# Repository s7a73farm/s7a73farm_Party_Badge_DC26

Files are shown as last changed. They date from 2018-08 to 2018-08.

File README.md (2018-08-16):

# s7a73farmsPartyBadge

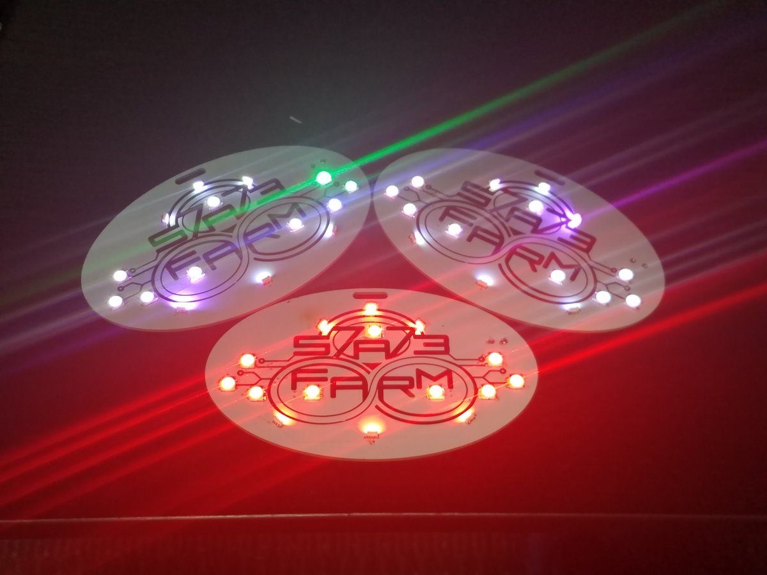
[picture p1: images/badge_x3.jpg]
s7a73farmsPartyBadge


# Getting Started to program it
```
Modify the tx/Makefile & rx/Makefile 
Line 16: AVRDUDE = avrdude -c usbasp -p t84 -U flash:w:$(PROJECT).hex
Change usbasp to usbtiny or whatever programmer  you are using.
```

## Build Master Badge
```
git clone git@github.com:SocialGeeks/s7a73farmsPartyBadge.git
cd firmware/tx
make clean
make
make upload
```

## Build Slave Badge
```
git clone git@github.com:SocialGeeks/s7a73farmsPartyBadge.git
cd firmware/rx
make clean
make
make upload
```

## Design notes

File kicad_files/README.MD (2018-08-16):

# FILES
---------------------
Gerbers zip

Kicad project zip

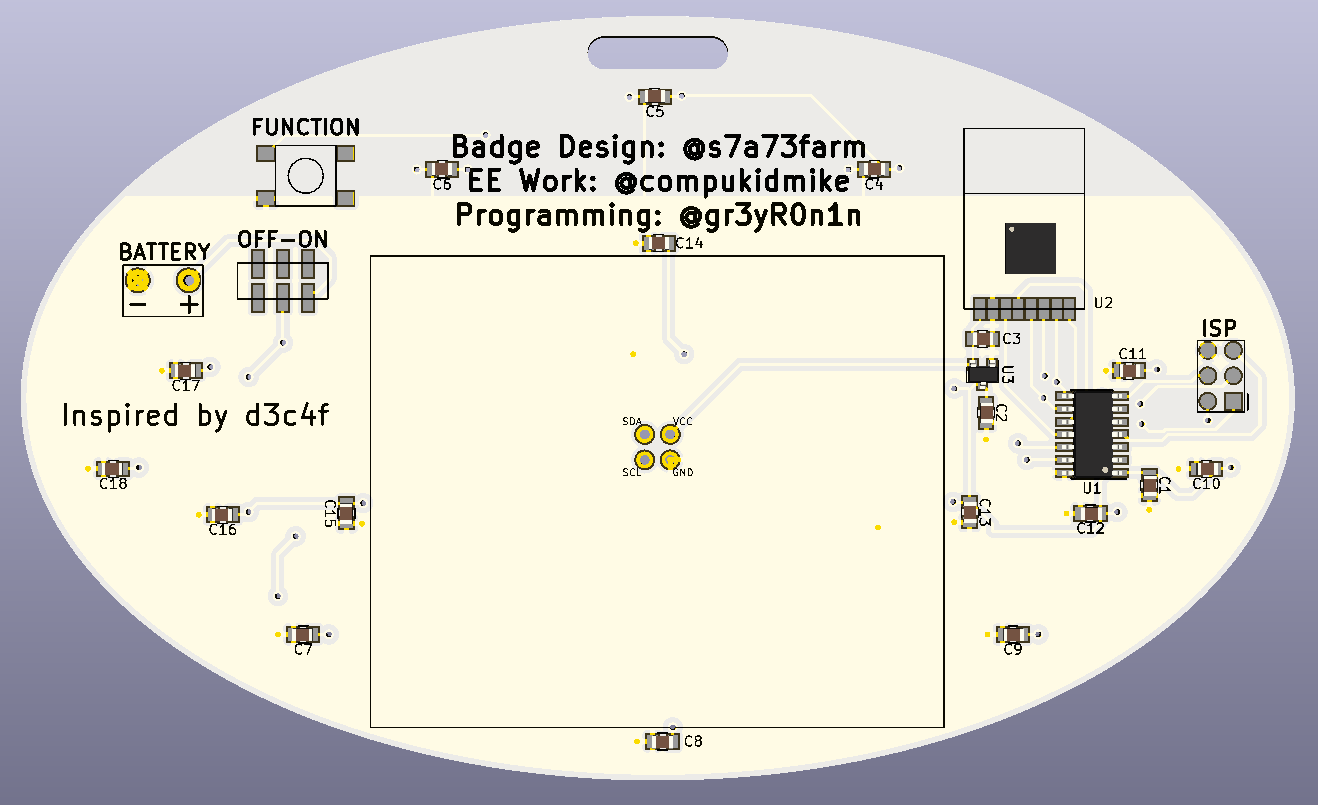
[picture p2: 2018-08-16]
images/Render2.PNG

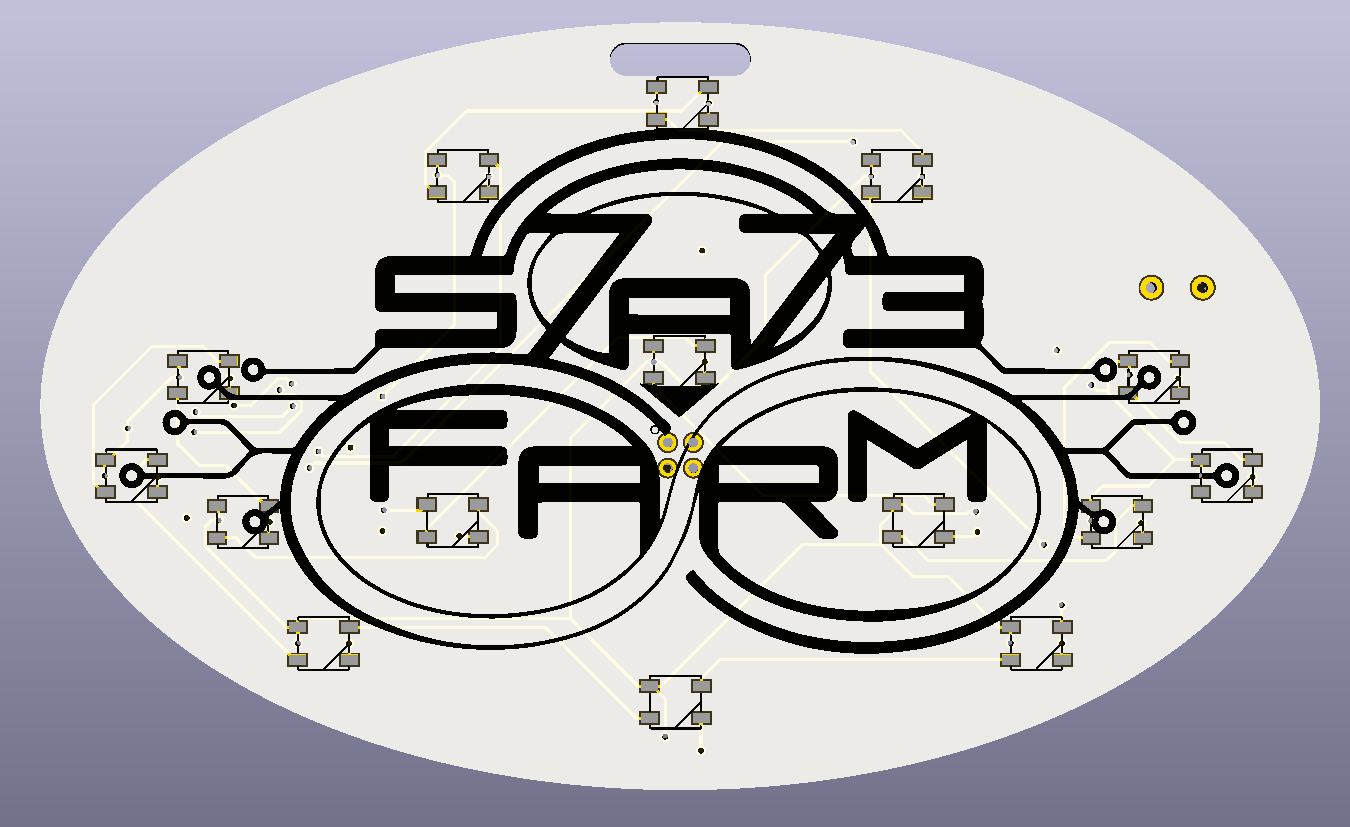
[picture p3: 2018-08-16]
images/Render1.PNG

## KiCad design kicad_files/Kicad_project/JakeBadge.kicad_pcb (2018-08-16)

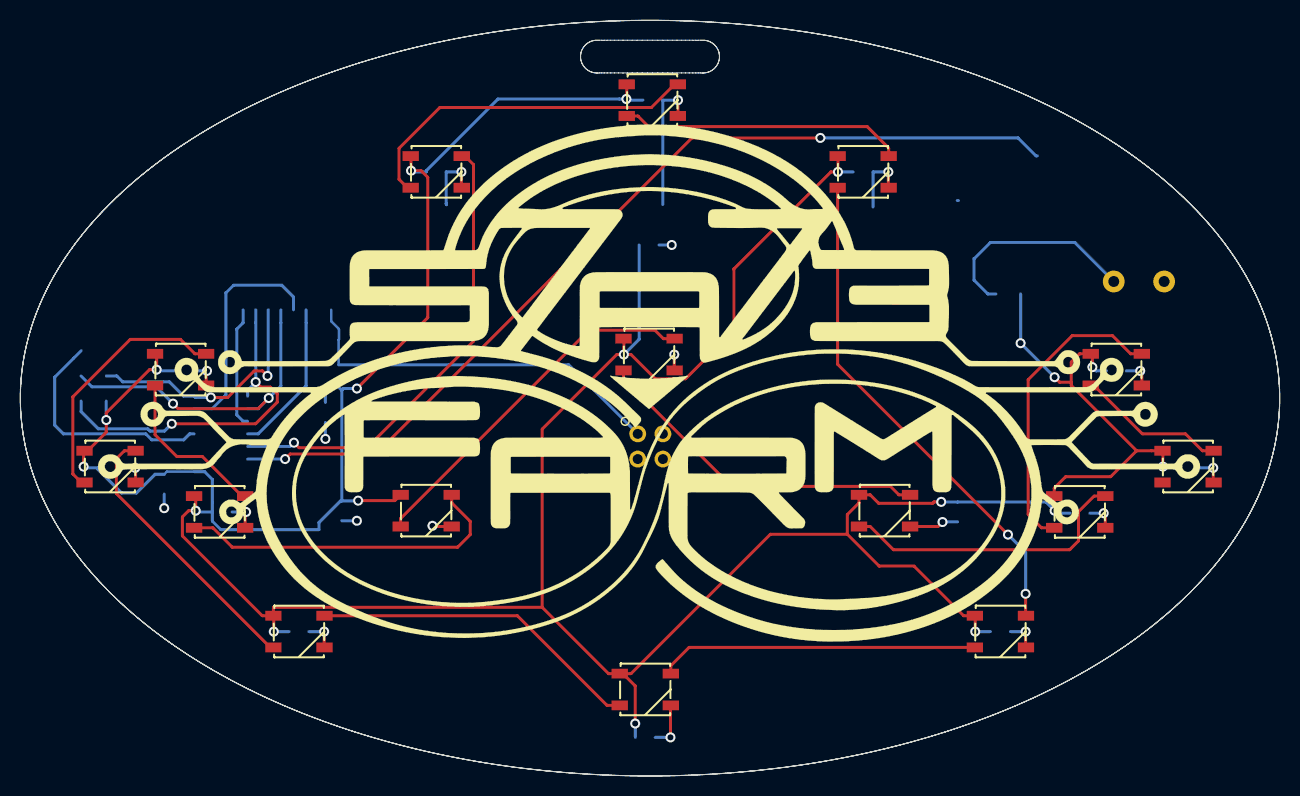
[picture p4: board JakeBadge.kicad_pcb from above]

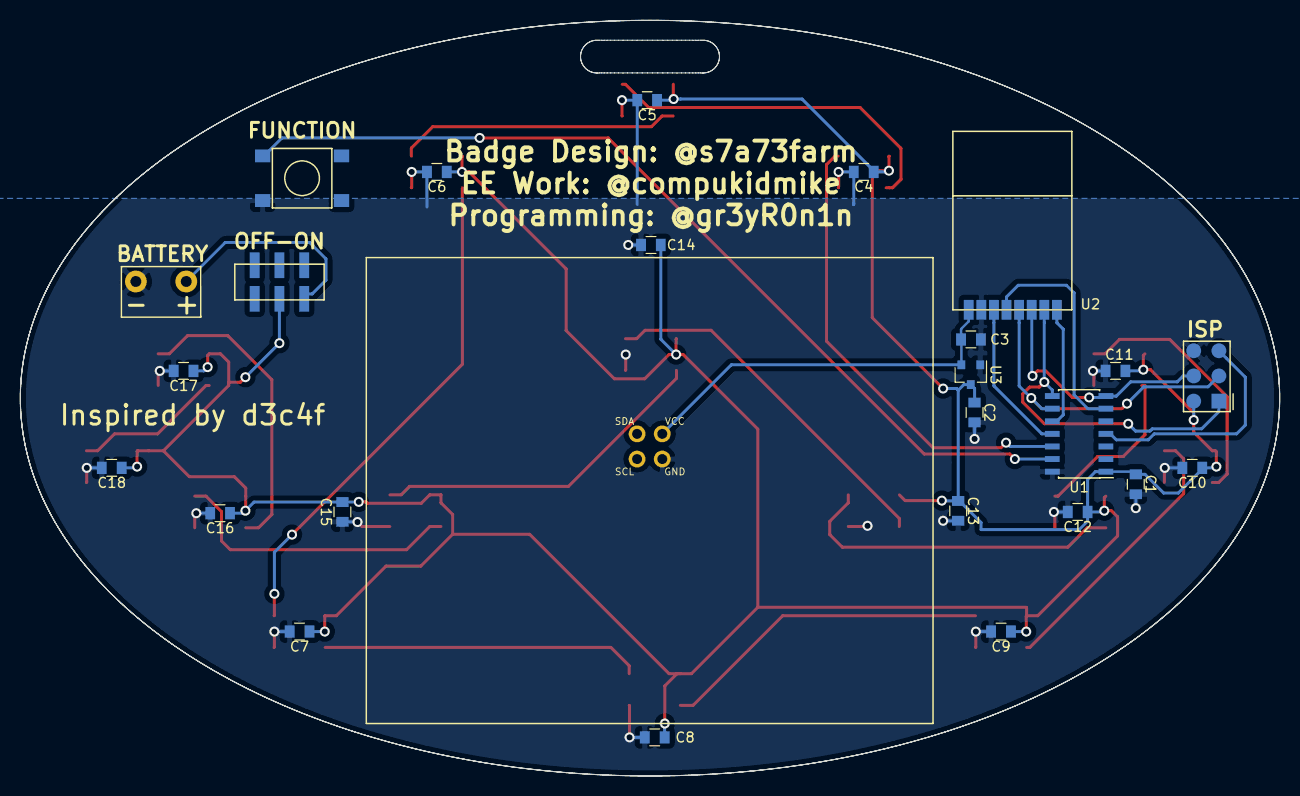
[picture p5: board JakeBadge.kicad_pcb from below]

Board: 2 copper layers, 127.0 x 76.2 mm, 41 parts (25 on the bottom side), 27 nets.

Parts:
BT1: Battery; Battery-WireConn
C1, C4, C5, C6, C7, C8, C9, C10, C11, C12, C13, C14, C15, C16, C17, C18: C_Small; C_0805
C2, C3: C; C_0805
CON1: AVR-ISP-6; ISP-AVR-6Pin-SMD
LED1, LED2, LED3, LED4, LED5, LED6, LED7, LED8, LED9, LED10, LED11, LED12, LED13, LED14, LED15: WS2812B
SW1: SW_SPST; JS202011JCQN
SW2: SW_Push; TACT-SMD
U1: ATTINY84A-SSU; SOIC-14_3.9x8.7mm_Pitch1.27mm
U2: NRF24L01; NRF24L01-SMD
U3: MCP1703A-3302_SOT23; SOT-23
X1: Badgelife_shitty_connector; Badgelife-Shitty-2x2

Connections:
+3V3: C3.1, U2.2, U3.2, X1.1
+BATT: C1.1, C2.1, C4.1, C5.1, C6.1, C7.1, C8.1, C9.1, C10.1, C11.1, C12.1, C13.1, C14.1, C15.1, C16.1, C17.1, C18.1, CON1.2, LED1.1, LED2.1, LED3.1, LED4.1, LED5.1, LED6.1, LED7.1, LED8.1, LED9.1, LED10.1, LED11.1, LED12.1, LED13.1, LED14.1, LED15.1, SW1.2, U1.1, U3.3
CE: U1.11, U2.3
CS: U1.6, U2.4
GND: BT1.2, C1.2, C2.2, C3.2, C4.2, C5.2, C6.2, C7.2, C8.2, C9.2, C10.2, C11.2, C12.2, C13.2, C14.2, C15.2, C16.2, C17.2, C18.2, CON1.6, LED1.3, LED2.3, LED3.3, LED4.3, LED5.3, LED6.3, LED7.3, LED8.3, LED9.3, LED10.3, LED11.3, LED12.3, LED13.3, LED14.3, LED15.3, SW2.2, U1.14, U2.1, U3.1, X1.2
IRQ: U1.10, U2.8
LED: LED1.4, U1.12
MISO: CON1.1, U1.8, U2.7
MOSI: CON1.4, U1.7, U2.6
unnamed: BT1.1, SW1.1
unnamed: LED1.2, LED2.4
unnamed: LED2.2, LED3.4
unnamed: LED3.2, LED4.4
unnamed: LED4.2, LED5.4
unnamed: LED5.2, LED6.4
unnamed: LED6.2, LED7.4
unnamed: LED7.2, LED8.4
unnamed: LED8.2, LED9.4
unnamed: LED10.2, LED11.4
unnamed: LED9.2, LED10.4
unnamed: LED11.2, LED12.4
unnamed: LED12.2, LED13.4
unnamed: LED13.2, LED14.4
unnamed: LED14.2, LED15.4
unnamed: SW2.1, U1.13
RST: CON1.5, U1.4
SCK: CON1.3, U1.9, U2.5

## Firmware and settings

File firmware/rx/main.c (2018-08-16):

/***********************************************************************
* FILENAME: main.c
* AUTHOR: s7a73farm, gr3yR0n1n
* DATE: 07.07.2018
*
* Copyright s7a73farm 2018.  All rights reserved.
***********************************************************************/


#include <avr/io.h>
#include <stdint.h>
#include <stdlib.h>
#include <avr/interrupt.h>
#include <util/delay.h>
#include "../debounce.h"
#include "../nrf24.h"
#include "../led_pattern.h"


// Master Sequences
#define unset           0x00
#define s7a73farm       0x10
#define wife            0x11
#define compukidmike    0x42
#define gr3yR0n1n       0x23


// Max number of patterns
#define LED_PHASE_MAX 4


// Globals
uint8_t led_phase = 0;
uint8_t party_mode = 0x00;
uint8_t party_count = 0x00;
uint8_t data_array[1];
uint8_t tx_address[5] = {0xA2,0xA2,0xA2,0xA2,0xA2};
uint8_t rx_address[5] = {0xD7,0xD7,0xD7,0xD7,0xD7};


// Called at about 100Hz (122Hz)
ISR(TIM0_OVF_vect) {
    // Debounce buttons. debounce() is declared static inline
    // in debounce.h so we will not suffer from the added overhead
    // of a (external) function call
    debounce(); 
    party_count++;
}


// System Init
void SystemInit(void) {
    SREG |= (1 << 7);    // set I bit in SREG

    // Timer0 normal mode, presc 1:256
    TCCR0B = 1<<CS02;
    // Overflow interrupt. (at 8e6/256/256 = 122 Hz)
    TIMSK0 = 1<<TOIE0;

    debounce_init();

    // Enable global interrupts
    sei();

    // Initialize LED
    led_init();
}


// Main
int main() {
    // ini interrupts	
    SystemInit();

    /* init hardware pins */
    nrf24_init();
    
    /* Channel #4 , payload length: 1 */
    nrf24_config(4,1);
 
    /* Set the device addresses */
    nrf24_tx_address(tx_address);
    nrf24_rx_address(rx_address);

    while(1) {
        if (party_count > 10) {
            party_count = 0;
            party_mode = 0x00;
        }

        if (party_mode == 0x00) {
            if(nrf24_dataReady()) {
                nrf24_getData(data_array);
                party_mode = data_array[0];
                
            	if (party_mode == s7a73farm) {		// s7a73farm
                    lets_party();
            	}
            	else if (party_mode == wife) {		// wife  
                    mrs_s7a73farm();
            	}
            	else if (party_mode == compukidmike) {	// compukidmike  
                    mk();
            	}
            	else if (party_mode == gr3yR0n1n) {	// gr3yR0n1n
		    ashen_colored_wanderer();
	    	}
            } 
            else {
                if (button_down(BUTTON1_MASK)) {
                    g_index = 0;
                    g_up = 1;
                    led_phase++;
                    no_party();
                    if (led_phase > LED_PHASE_MAX) { led_phase = 0;}
                }
			
                if (led_phase == 0) {
		    //ashen_colored_wanderer();
                    phantom();
                }
                else if (led_phase == 1) {
                    computations();
                }
                else if (led_phase == 2) {
                    knight_rider();
                }
                else if (led_phase == 3) {
                    lady_bug();
                }
                else if (led_phase == 4) {
                    rainbow_fade();
                }
            }
        } 
        else {
            if (party_mode == s7a73farm) {		// s7a73farm
                lets_party();
            }
            else if (party_mode == wife) {		// wife  
                mrs_s7a73farm();
            }
            else if (party_mode == compukidmike) {	// compukidmike  
                mk();
            }
            else if (party_mode == gr3yR0n1n) {		// gr3yR0n1n
		ashen_colored_wanderer();
	    }
        }
    }
}

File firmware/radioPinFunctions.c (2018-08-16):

/***********************************************************************
* FILENAME: radioPinFunctions.c
* AUTHOR: s7a73farm, gr3yR0n1n
* DATE: 07.07.2018
*
* Copyright s7a73farm 2018.  All rights reserved.
***********************************************************************/

#include <avr/io.h>

#define set_bit(reg,bit) reg |= (1<<bit)
#define clr_bit(reg,bit) reg &= ~(1<<bit)
#define check_bit(reg,bit) (reg&(1<<bit))

/* ------------------------------------------------------------------------- */
void nrf24_setupPins() {
	/*
    set_bit(DDRA,0); // CE output
    set_bit(DDRA,1); // CSN output
    set_bit(DDRA,2); // SCK output
    set_bit(DDRA,3); // MOSI output
    clr_bit(DDRA,4); // MISO input
	*/
	set_bit(DDRA,2); // CE output
	set_bit(DDRA,7); // CSN output
	set_bit(DDRA,4); // SCK output
	set_bit(DDRA,6); // MOSI output
	clr_bit(DDRA,5); // MISO input
}
/* ------------------------------------------------------------------------- */
void nrf24_ce_digitalWrite(uint8_t state) {
    if(state) {
        set_bit(PORTA,2);
    }
    else {
        clr_bit(PORTA,2);
    }
}
/* ------------------------------------------------------------------------- */
void nrf24_csn_digitalWrite(uint8_t state) {
    if(state) {
        set_bit(PORTA,7);
    }
    else {
        clr_bit(PORTA,7);
    }
}
/* ------------------------------------------------------------------------- */
void nrf24_sck_digitalWrite(uint8_t state) {
    if(state) {
        set_bit(PORTA,4);
    }
    else {
        clr_bit(PORTA,4);
    }
}
/* ------------------------------------------------------------------------- */
void nrf24_mosi_digitalWrite(uint8_t state) {
    if(state) {
        set_bit(PORTA,6);
    }
    else {
        clr_bit(PORTA,6);
    }
}
/* ------------------------------------------------------------------------- */
uint8_t nrf24_miso_digitalRead() {
    return check_bit(PINA,5);
}
/* ------------------------------------------------------------------------- */
